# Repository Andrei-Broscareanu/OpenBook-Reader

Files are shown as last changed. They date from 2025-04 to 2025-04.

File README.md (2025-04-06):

# 📖 eBook Reader Portabil – ESP32-C6 Edition

Un eBook Reader cu consum redus, afișaj E-Ink și conectivitate modernă (Wi-Fi 6 & Bluetooth 5), construit în jurul microcontrollerului **ESP32-C6-WROOM-1-N8**.

---

## 🔧 Arhitectură Hardware

### 🧠 Microcontroller
- **ESP32-C6-WROOM-1-N8**
  - RISC-V core
  - Wi-Fi 6 și Bluetooth 5
  - Criptografie hardware integrată
  - Interfețe: SPI, I2C, GPIO

### 💾 Memorie
- **64MB NOR Flash** – W25Q512JVEIQ, conectată prin SPI
- **Slot microSD** – pentru stocare eBooks, conectat pe SPI separat

### 🔋 Alimentare
- **USB-C (PMF0501)** – intrare standard 5V
- **Protecție ESD (USBLC6-2SC6Y)** – pentru liniile USB
- **Încărcător Li-Po (MCP73831)** – pentru o celulă 3.7V, max 500mA
- **Baterie Li-Po 3.7V** – autonomie extinsă
- **Regulator LDO (MCP1700-3302E)** – convertește 5V la 3.3V

---

## 🖼️ Afișaj E-Ink

- Conector pentru ecrane de **1.54" E-Paper (200x200px)**
- Interfață: **SPI + GPIO**
- Circuit de alimentare:
  - Transistor Q3
  - Inductor L1
  - Diodă D2
- **Selector SJ1** – pentru tipul de display

---

## 📦 Periferice & Senzori

| Componentă | Funcție | Interfață | Pini ESP32-C6 |
|---|---|---|---|
| **BME688** | Temperatură, umiditate, presiune, VOCs | I2C | GPIO1 (SDA), GPIO2 (SCL) |
| **DS3231SN** | RTC – ceas timp real | I2C | GPIO1 (SDA), GPIO2 (SCL) |
| **MAX17048G-T10** | Fuel gauge baterie | I2C | GPIO1 (SDA), GPIO2 (SCL) |
| **Buton Reset** | Sistem reset | GPIO | GPIO0 |
| **Buton Boot** | Bootloader | GPIO | GPIO3 |
| **Qwiic/Stemma QT**| Extensii rapide I2C | I2C | GPIO1 (SDA), GPIO2 (SCL) |

---

## 🔌 Pini utilizați pe ESP32-C6

| Componentă | Interfață | Pini ESP32-C6 | Observații |
|---|---|---|---|
| SD Card | SPI | GPIO10, GPIO11, GPIO12, GPIO13 | Bus SPI dedicat |
| NOR Flash | SPI | GPIO6, GPIO7, GPIO8, GPIO9 | Bus SPI separat |
| E-Ink Display | SPI + GPIO | GPIO18, GPIO19, GPIO20, GPIO21 | Control ecran |
| Senzori + RTC | I2C | GPIO1 (SDA), GPIO2 (SCL) | Comun I2C |
| Butoane sistem | GPIO | GPIO0 (RST), GPIO3 (BOOT) | Control utilizator |
| Test Pads | GPIO/UART | GPIO17, GPIO22 | Debug/UART |

---

## ⚡ Estimare consum de energie

| Modul | Consum aproximativ |
|---|---|
| ESP32-C6 activ | ~80-100 mA |
| ESP32-C6 deep sleep | ~10 µA |
| E-Ink refresh | ~25 mA (temporar) |
| SD Card idle / acces | ~2 mA / ~50 mA |
| RTC + BME688 standby | ~3-5 µA |
| MAX17048 | ~3 µA |

**Autonomie estimată cu baterie Li-Po 500mAh:**
- Utilizare normală: **15-20 ore**
- Standby (deep sleep): **până la câteva săptămâni**

---

## 🧩 Design PCB și carcasă

- Blocuri separate: alimentare, MCU, afișaj, senzori
- Plan de masă comun și trasee optimizate
- Conectori accesibili extern (USB, afisaj, butoane)
- Carcasă 3D ergonomică și compactă
- Randări 3D disponibile

---

## ✅ Status proiect

- [x] Hardware complet funcțional
- [x] PCB finalizat și validat
- [x] Carcasă 3D completă
- [x] Optimizare consum energetic
- [x] Conectivitate Wi-Fi 6 și Bluetooth 5

---

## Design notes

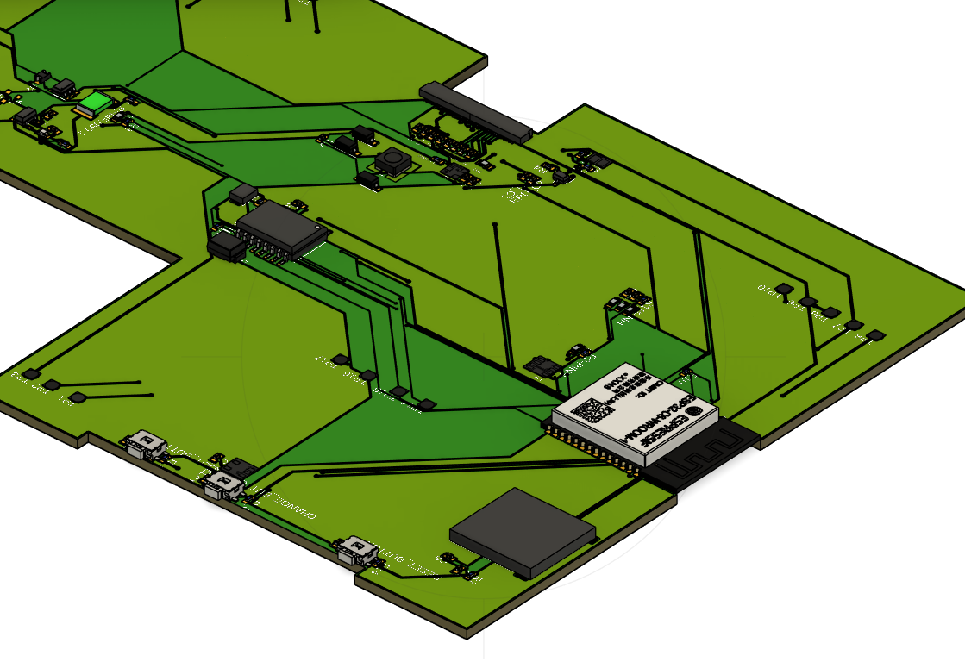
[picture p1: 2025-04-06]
Images/Captură de ecran 2025-04-06 132129.png

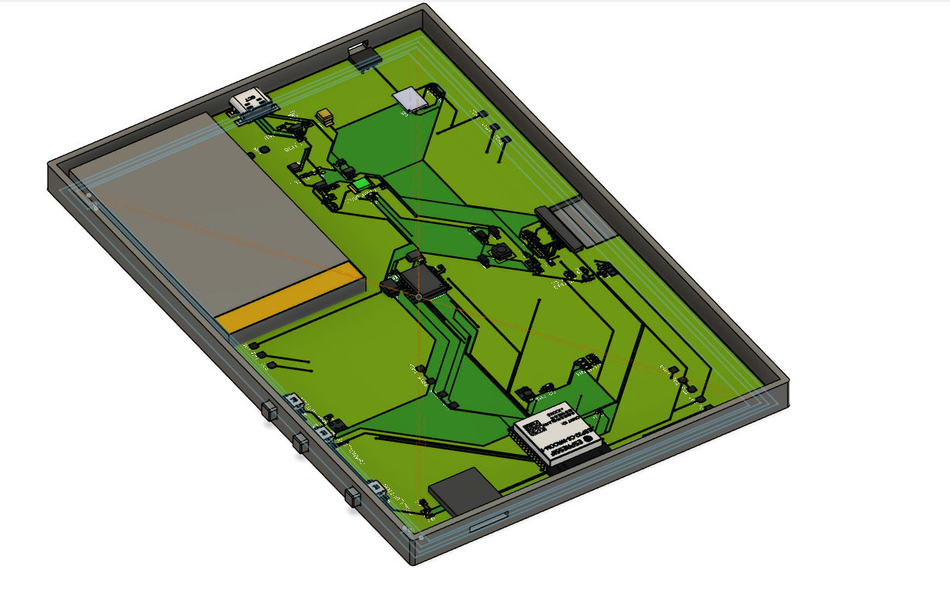
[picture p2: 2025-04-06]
Images/Captură de ecran 2025-04-06 132329.png

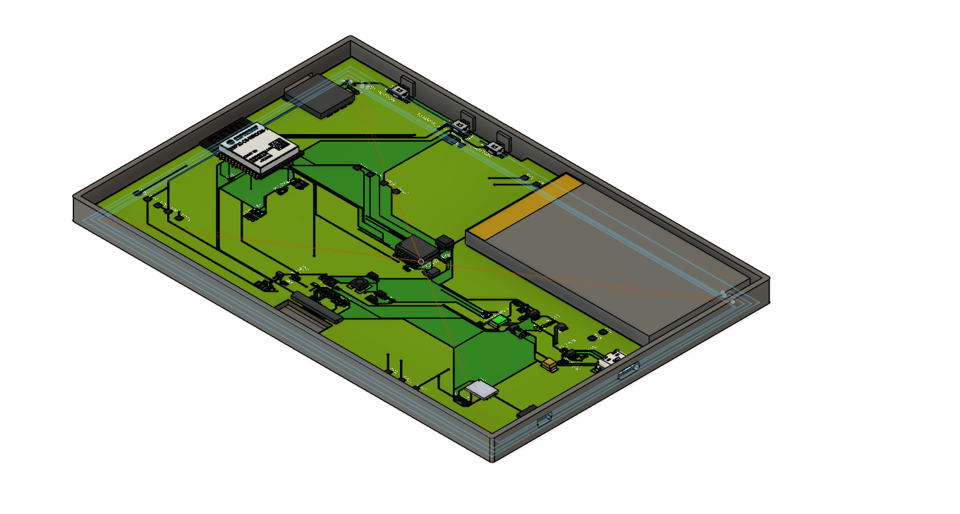
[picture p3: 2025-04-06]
Images/Captură de ecran 2025-04-06 132304.png

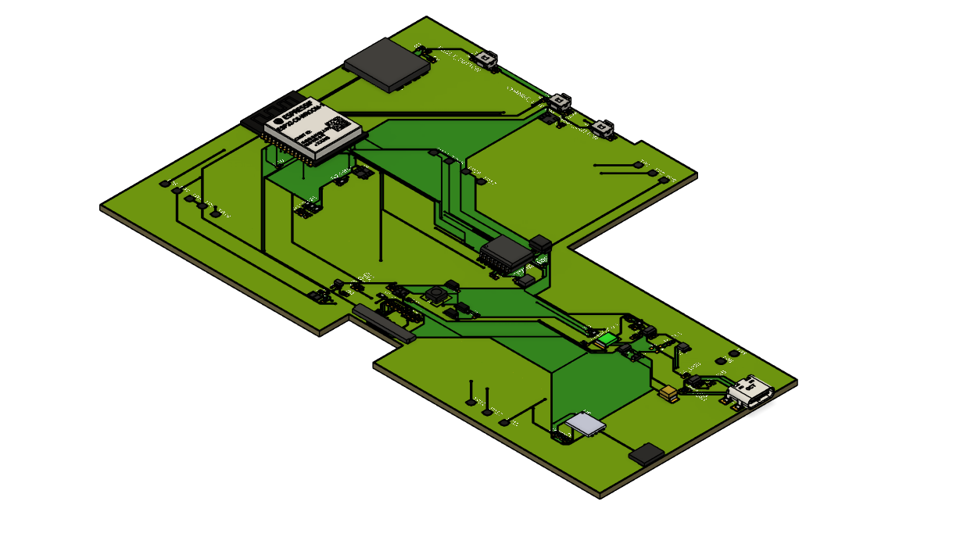
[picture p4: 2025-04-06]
Images/Captură de ecran 2025-04-06 130139.png

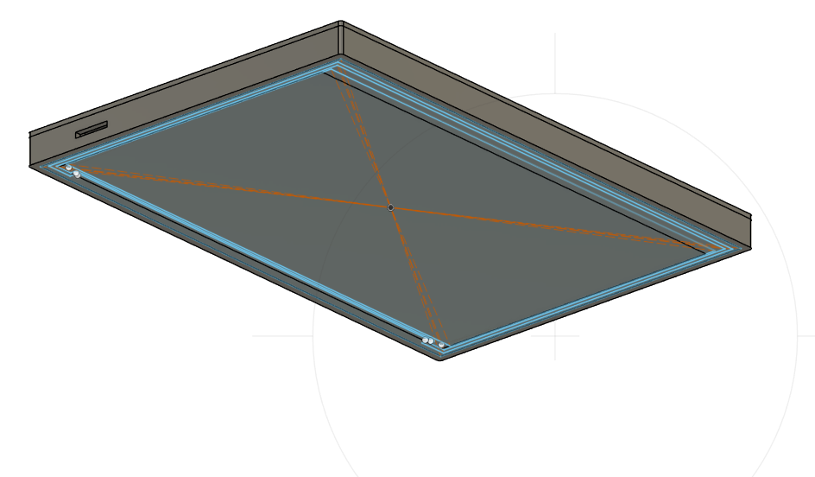
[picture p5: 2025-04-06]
Images/Captură de ecran 2025-04-06 132404.png

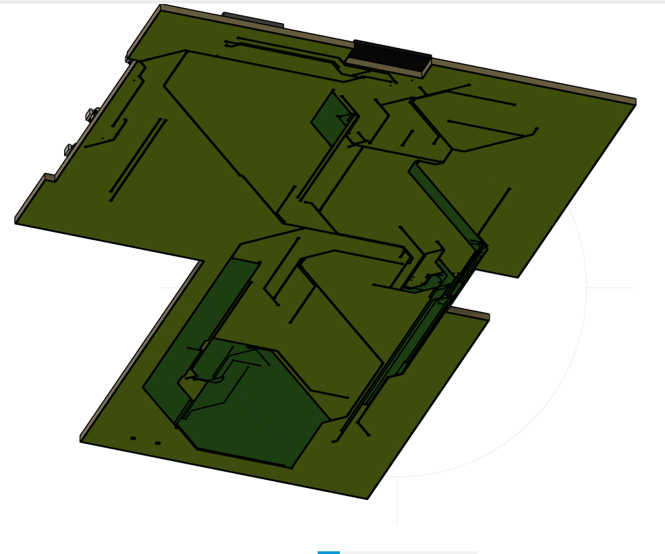
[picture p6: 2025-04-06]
Images/Captură de ecran 2025-04-06 132156.png

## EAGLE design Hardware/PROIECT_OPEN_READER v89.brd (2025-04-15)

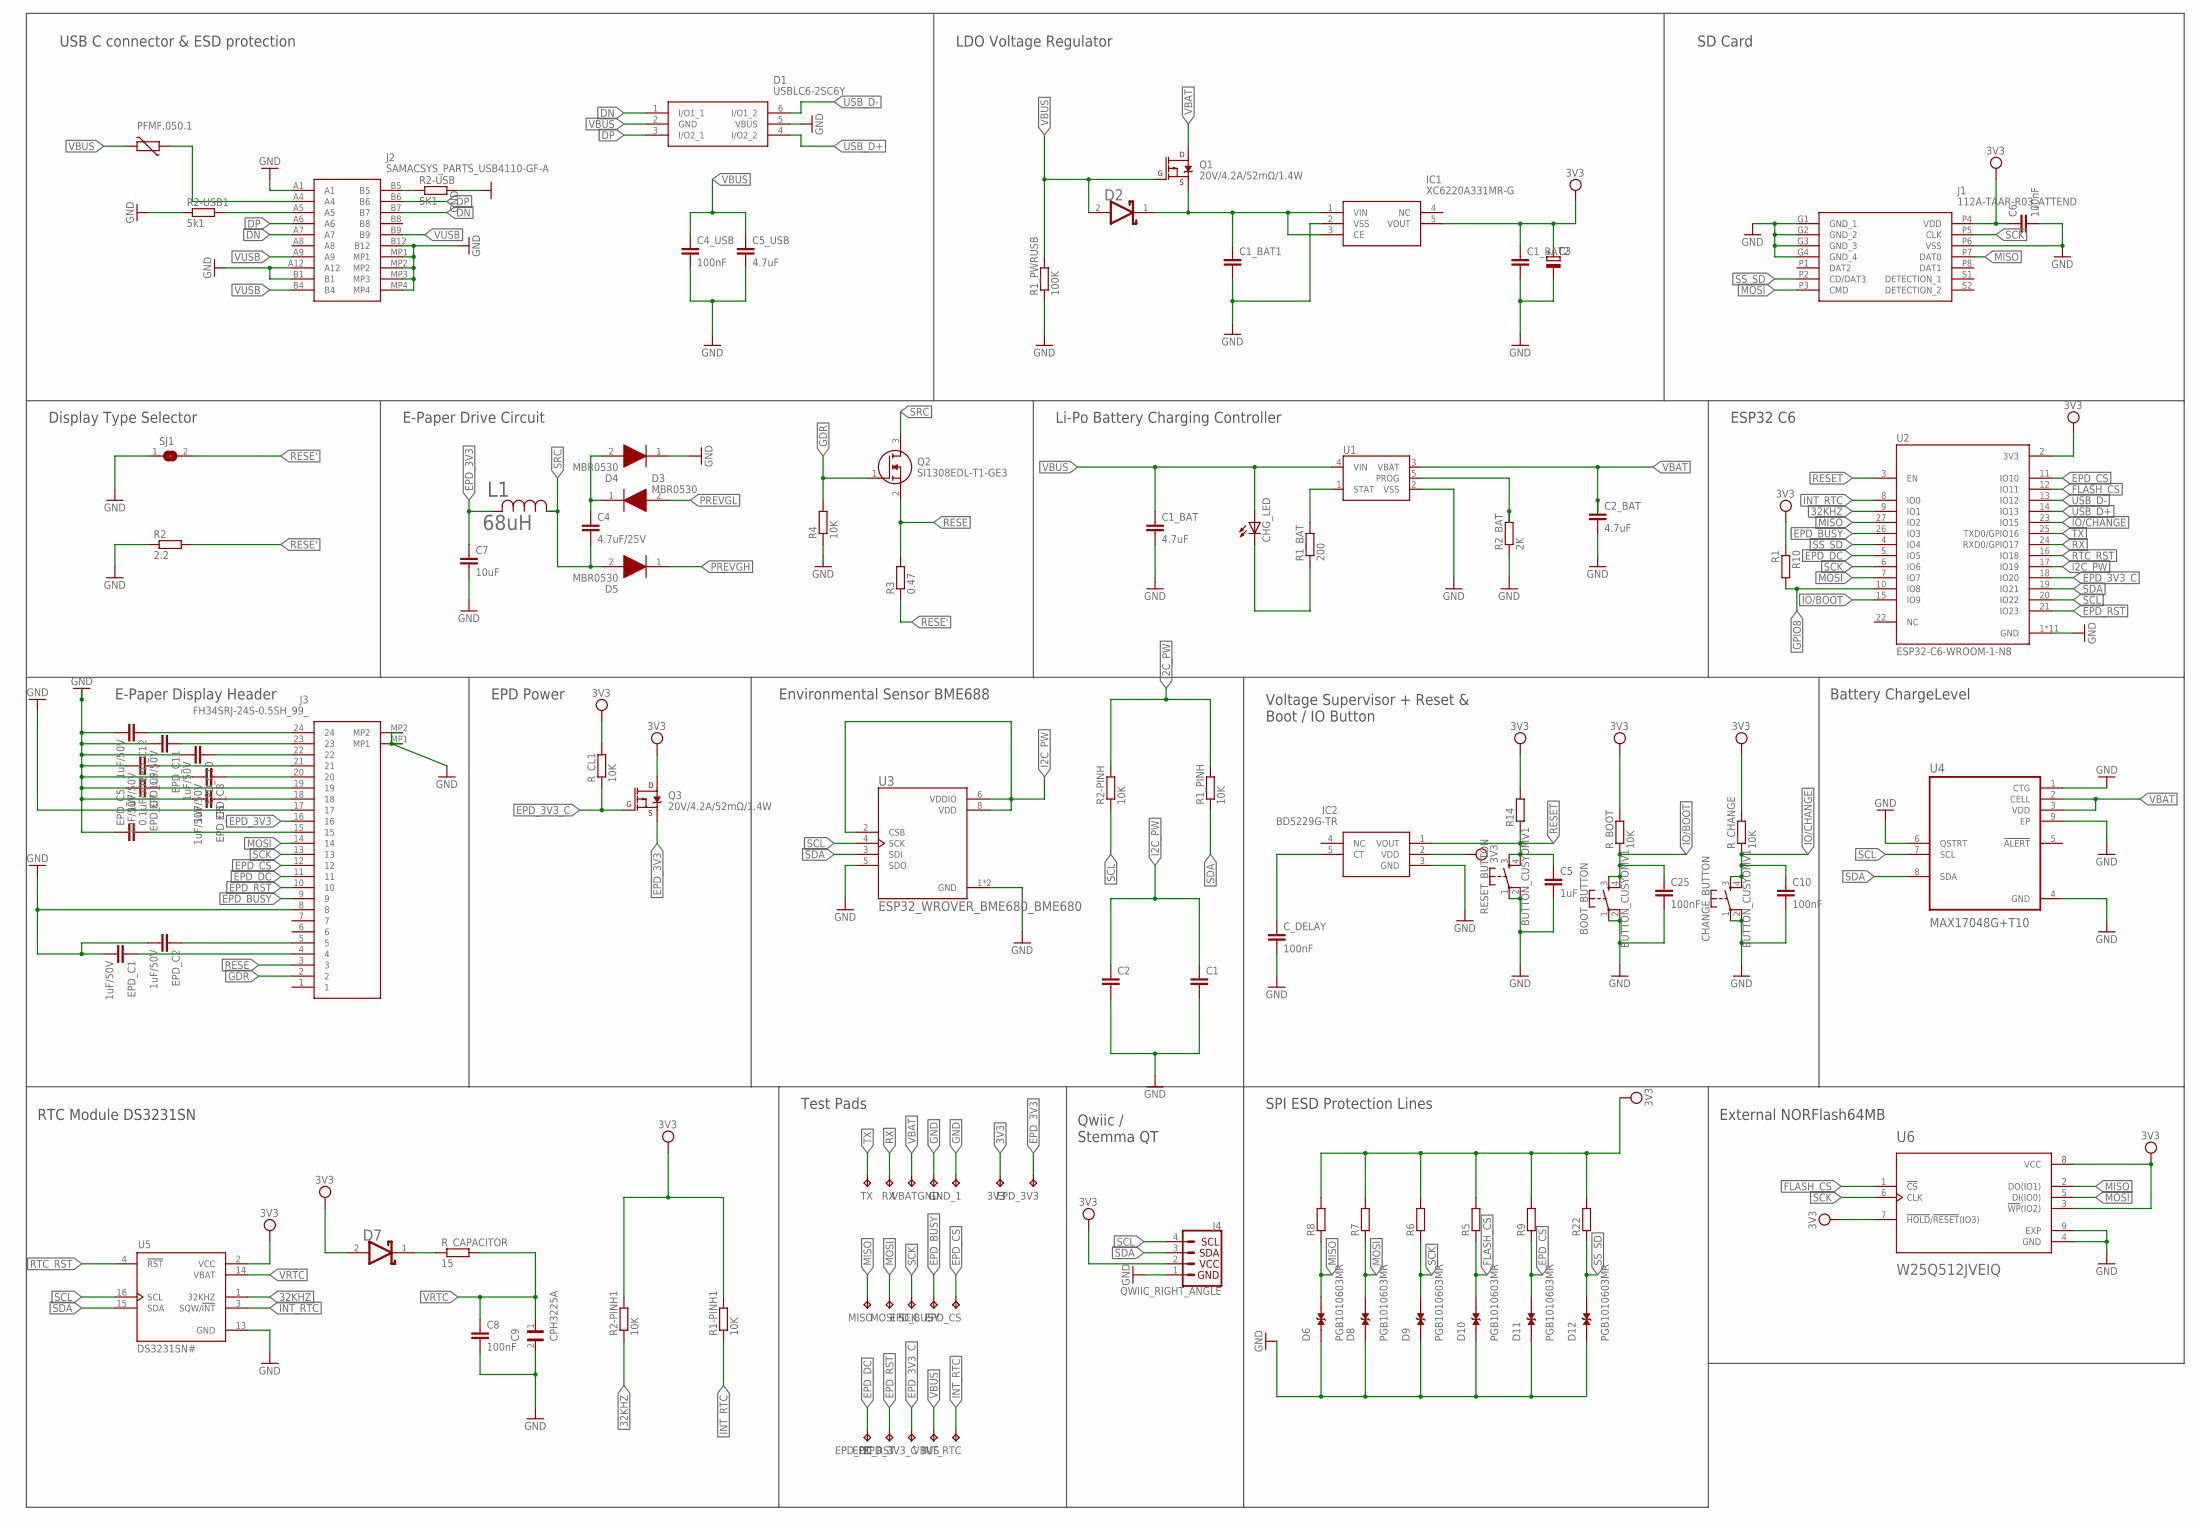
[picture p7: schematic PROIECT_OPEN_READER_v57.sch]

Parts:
3V3: TPTP20R; TP20R
BOOT_BUTTON: BUTTON_CUSYOMV1; MYBUTTON
C1, C1_BAT1, C1_BAT2, C2: EAGLE-LTSPICE_CC0402; EAGLE-LTSPICE_C0402
C1_BAT, C2_BAT, C5_USB: 4.7uF; EAGLE-LTSPICE_C0402
C3: RCL_CPOL-EUCT3528; RCL_CT3528
C4: 4.7uF/25V; EAGLE-LTSPICE_C0402
C4_USB, C6, C8, C10, C25: 100nF; EAGLE-LTSPICE_C0402
C5: 1uF; EAGLE-LTSPICE_C0402
C7: 10uF; EAGLE-LTSPICE_C0402
C9: CPH3225A; CAPCP3225X100N
CHANGE_BUTTON: BUTTON_CUSYOMV1; MYBUTTON
CHG_LED: ADAFRUIT_LEDCHIP-LED0603; ADAFRUIT_CHIP-LED0603
C_DELAY: 100nF; EAGLE-LTSPICE_C0402
D1: USBLC6-2SC6Y; SOT95P280X145-6N
D2, D7: ESP32_WROVER_AVX---SD0805S020S1R0_AVX_SD0805S020S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; ESP32_WROVER_AVX---SD0805S020S1R0_AVX_SD0805S020S1R0_0
D3, D4, D5: MBR0530; SOD3716X135N
D6, D8, D9, D10, D11, D12: PGB1010603MR; DIOC1608X36N
EPD_3V3, EPD_3V3_C: TPTP20R; TP20R
EPD_BUSY: TPTP20R; TP20R
EPD_C1, EPD_C2, EPD_C6, EPD_C7, EPD_C8, EPD_C9, EPD_C10, EPD_C11, EPD_C12: 1uF/50V; EAGLE-LTSPICE_C0402
EPD_C5: 0.1uF/50V; EAGLE-LTSPICE_C0402
EPD_CS: TPTP20R; TP20R
EPD_DC: TPTP20R; TP20R
EPD_RST: TPTP20R; TP20R
GND: TPTP20R; TP20R
GND_1: TPTP20R; TP20R
IC1: XC6220A331MR-G; SOT95P280X120-5N
IC2: BD5229G-TR; SOT95P280X125-5N
INT_RTC: TPTP20R; TP20R
J1: 112A-TAAR-R03_ATTEND; 112ATAARR03ATTEND
J2: SAMACSYS_PARTS_USB4110-GF-A; SAMACSYS_PARTS_USB4110GFA
J3: FH34SRJ-24S-0.5SH_99_; FH34SRJ24S05SH99
J4: QWIIC_RIGHT_ANGLE; JST04_1MM_RA
L1: 68uH; IND_4828-WE-TPC_WRE
MISO: TPTP20R; TP20R
MOSI: TPTP20R; TP20R
PFMF.050.1: ESP32C6_VARISTORCN1812; ESP32C6_VARISTOR_CT/CN1812
Q1, Q3: 20V/4.2A/52mΩ/1.4W; ESP32_WROVER_SPARKFUN-DISCRETESEMI_SOT23-3
Q2: SI1308EDL-T1-GE3; SOT65P210X110-3N
R1-PINH1, R1_PINH, R2-PINH, R2-PINH1, R4: 10K; ESP32_WROVER_EAGLE-LTSPICE_R0402
R1_BAT: 200; ESP32_WROVER_EAGLE-LTSPICE_R0402
R1_PWRUSB: 100K; ESP32_WROVER_EAGLE-LTSPICE_R0402
R2: 2.2; ESP32_WROVER_EAGLE-LTSPICE_R0402
R2-USB: 5K1; ESP32_WROVER_EAGLE-LTSPICE_R0402
R2-USB1: 5k1; ESP32_WROVER_EAGLE-LTSPICE_R0402
R2_BAT: 2K; ESP32_WROVER_EAGLE-LTSPICE_R0402
R3: 0.47; ESP32_WROVER_EAGLE-LTSPICE_R0402
R5, R6, R7, R8, R9, R14, R22: ESP32_WROVER_EAGLE-LTSPICE_RR0402; ESP32_WROVER_EAGLE-LTSPICE_R0402
R10: R1; ESP32_WROVER_EAGLE-LTSPICE_R0402
RESET_BUTTON: BUTTON_CUSYOMV1; MYBUTTON
RX: TPTP20R; TP20R
R_BOOT: 10K; ESP32_WROVER_EAGLE-LTSPICE_R0402
R_CAPACITOR: 15; ESP32_WROVER_EAGLE-LTSPICE_R0402
R_CHANGE: 10K; ESP32_WROVER_EAGLE-LTSPICE_R0402
R_CL1: 10K; ESP32_WROVER_EAGLE-LTSPICE_R0402
SCK: TPTP20R; TP20R
SJ1: SJ
TX: TPTP20R; TP20R
U1: ESP32_WROVER_SPARKFUN-IC-POWER_MCP73831; ESP32_WROVER_SPARKFUN-IC-POWER_SOT23-5
U2: ESP32-C6-WROOM-1-N8; XCVR_ESP32-C6-WROOM-1-N8
U3: ESP32_WROVER_BME680_BME680; ESP32_WROVER_BME680_PSON80P300X300X100-8N
U4: MAX17048G+T10; SON50P200X200X80-9N
U5: DS3231SN#; SOIC127P1032X265-16N
U6: W25Q512JVEIQ; SON127P600X800X80-9N
VBAT: TPTP20R; TP20R
VBUS: TPTP20R; TP20R

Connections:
3V3: 3V3.TP, C1_BAT2.1, C3.+, C6.1, D7.2 (ANODE), IC1.5 (VOUT), IC2.2 (VDD), J1.P4 (VDD), J4.2, Q3.3 (D), R1-PINH1.2, R2-PINH1.2, R5.2, R6.2, R7.2, R8.2, R9.2, R10.1, R14.2, R22.2, R_BOOT.2, R_CHANGE.2, R_CL1.2, U2.2 (3V3), U5.2 (VCC), U6.3 (!WP!(IO2)), U6.7 (!HOLD!/!RESET!(IO3)), U6.8 (VCC)
32KHZ: R2-PINH1.1, U2.9 (IO1), U5.1 (32KHZ)
DN: D1.1 (I/O1_1), J2.A7, J2.B7
DP: D1.3 (I/O2_1), J2.A6, J2.B6
EPD_3V3: C7.1, EPD_3V3.TP, J3.16, L1.2, Q3.2 (S)
EPD_3V3_C: EPD_3V3_C.TP, Q3.1 (G), R_CL1.1, U2.18 (IO20)
EPD_BUSY: EPD_BUSY.TP, J3.9, U2.26 (IO3)
EPD_CS: D11.2, EPD_CS.TP, J3.12, R9.1, U2.11 (IO10)
EPD_DC: EPD_DC.TP, J3.11, U2.5 (IO5)
EPD_RST: EPD_RST.TP, J3.10, U2.21 (IO23)
FLASH_CS: D10.2, R5.1, U2.12 (IO11), U6.1 (!CS)
GDR: J3.2, Q2.1 (G), R4.2
GND: BOOT_BUTTON.1, BOOT_BUTTON.2, C1.2, C1_BAT.2, C1_BAT1.2, C1_BAT2.2, C2.2, C2_BAT.2, C3.-, C4_USB.2, C5.2, C5_USB.2, C6.2, C7.2, C8.2, C9.2, C10.2, C25.2, CHANGE_BUTTON.1, CHANGE_BUTTON.2, C_DELAY.2, D1.5 (VBUS), D4.1 (K), D6.1, D8.1, D9.1, D10.1, D11.1, D12.1, EPD_C1.2, EPD_C2.2, EPD_C5.1, EPD_C6.2, EPD_C7.2, EPD_C8.2, EPD_C9.2, EPD_C10.2, EPD_C11.2, EPD_C12.2, GND.TP, GND_1.TP, IC1.2 (VSS), IC2.3 (GND), J1.G1 (GND_1), J1.G2 (GND_2), J1.G3 (GND_3), J1.G4 (GND_4), J1.P6 (VSS), J2.A1, J2.A12, J2.B1, J2.B12, J2.MP1, J2.MP2, J2.MP3, J2.MP4, J3.8, J3.17, J3.MP1, J3.MP2, J4.1, R1_PWRUSB.1, R2.1, R2-USB.2, R2-USB1.1, R2_BAT.1, R4.1, RESET_BUTTON.1, RESET_BUTTON.2, SJ1.1, U1.2 (VSS), U2.1 (GND), U2.28 (GND), U2.29_1 (GND), U2.29_2 (GND), U2.29_3 (GND), U2.29_4 (GND), U2.29_5 (GND), U2.29_6 (GND), U2.29_7 (GND), U2.29_8 (GND), U2.29_9 (GND), U3.1 (GND), U3.5 (SDO), U3.7 (GND), U4.1 (CTG), U4.4 (GND), U4.6 (QSTRT), U4.9 (EP), U5.13 (GND), U6.4 (GND), U6.9 (EXP)
GPIO8: R10.2, U2.10 (IO8)
I2C_PW: C1.1, C2.1, R1_PINH.2, R2-PINH.2, U2.17 (IO19), U3.2 (CSB), U3.6 (VDDIO), U3.8 (VDD)
INT_RTC: INT_RTC.TP, R1-PINH1.1, U2.8 (IO0), U5.3 (SQW/!INT)
IO/BOOT: BOOT_BUTTON.3, BOOT_BUTTON.4, C25.1, R_BOOT.1, U2.15 (IO9)
IO/CHANGE: C10.1, CHANGE_BUTTON.3, CHANGE_BUTTON.4, R_CHANGE.1, U2.23 (IO15)
MISO: D6.2, J1.P7 (DAT0), MISO.TP, R8.1, U2.27 (IO2), U6.2 (DO(IO1))
MOSI: D8.2, J1.P3 (CMD), J3.14, MOSI.TP, R7.1, U2.7 (IO7), U6.5 (DI(IO0))
unnamed: J2.A4, PFMF.050.1.1
unnamed: J2.A5, R2-USB1.2
unnamed: J2.B5, R2-USB.1
unnamed: C1_BAT1.1, D2.1 (CATHODE), IC1.1 (VIN), IC1.3 (CE), Q1.2 (S)
unnamed: EPD_C12.1, J3.24
unnamed: EPD_C11.1, J3.23
unnamed: C4.1, D3.1 (K), D4.2 (A)
unnamed: R2_BAT.2, U1.5 (PROG)
unnamed: EPD_C10.1, J3.22
unnamed: EPD_C9.1, J3.21
unnamed: CHG_LED.C, R1_BAT.1
unnamed: R1_BAT.2, U1.1 (STAT)
unnamed: EPD_C8.1, J3.20
unnamed: EPD_C7.1, J3.19
unnamed: EPD_C6.1, J3.18
unnamed: C_DELAY.1, IC2.5 (CT)
unnamed: EPD_C5.2, J3.15
unnamed: EPD_C2.1, J3.5
unnamed: EPD_C1.1, J3.4
unnamed: D7.1 (CATHODE), R_CAPACITOR.1
PREVGH: D5.1 (K)
PREVGL: D3.2 (A)
RESE: J3.3, Q2.2 (S), R3.2
RESE': R2.2, R3.1, SJ1.2
RESET: C5.1, IC2.1 (VOUT), R14.1, RESET_BUTTON.3, RESET_BUTTON.4, U2.3 (EN)
RTC_RST: U2.16 (IO18), U5.4 (!RST)
RX: RX.TP, U2.24 (RXD0/GPIO17)
SCK: D9.2, J1.P5 (CLK), J3.13, R6.1, SCK.TP, U2.6 (IO6), U6.6 (CLK)
SCL: J4.4, R2-PINH.1, U2.20 (IO22), U3.4 (SCK), U4.7 (SCL), U5.16 (SCL)
SDA: J4.3, R1_PINH.1, U2.19 (IO21), U3.3 (SDI), U4.8 (SDA), U5.15 (SDA)
SRC: C4.2, D5.2 (A), L1.1, Q2.3 (D)
SS_SD: D12.2, J1.P2 (CD/DAT3), R22.1, U2.4 (IO4)
TX: TX.TP, U2.25 (TXD0/GPIO16)
USB_D+: D1.4 (I/O2_2), U2.14 (IO13)
USB_D-: D1.6 (I/O1_2), U2.13 (IO12)
VBAT: C2_BAT.1, Q1.3 (D), U1.3 (VBAT), U4.2 (CELL), U4.3 (VDD), VBAT.TP
VBUS: C1_BAT.1, C4_USB.1, C5_USB.1, CHG_LED.A, D1.2 (GND), D2.2 (ANODE), PFMF.050.1.2, Q1.1 (G), R1_PWRUSB.2, U1.4 (VIN), VBUS.TP
VRTC: C8.1, C9.1, R_CAPACITOR.2, U5.14 (VBAT)
VUSB: J2.A9, J2.B4, J2.B9

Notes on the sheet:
USB C connector & ESD protection
LDO Voltage Regulator
SD Card
Display Type Selector
E-Paper Drive Circuit
Li-Po Battery Charging Controller
ESP32 C6
E-Paper Display Header
EPD Power
Environmental Sensor BME688
Voltage Supervisor + Reset & Boot / IO Button
Battery ChargeLevel
RTC Module DS3231SN
Test Pads
Qwiic / Stemma QT
SPI ESD Protection Lines
External NORFlash64MB

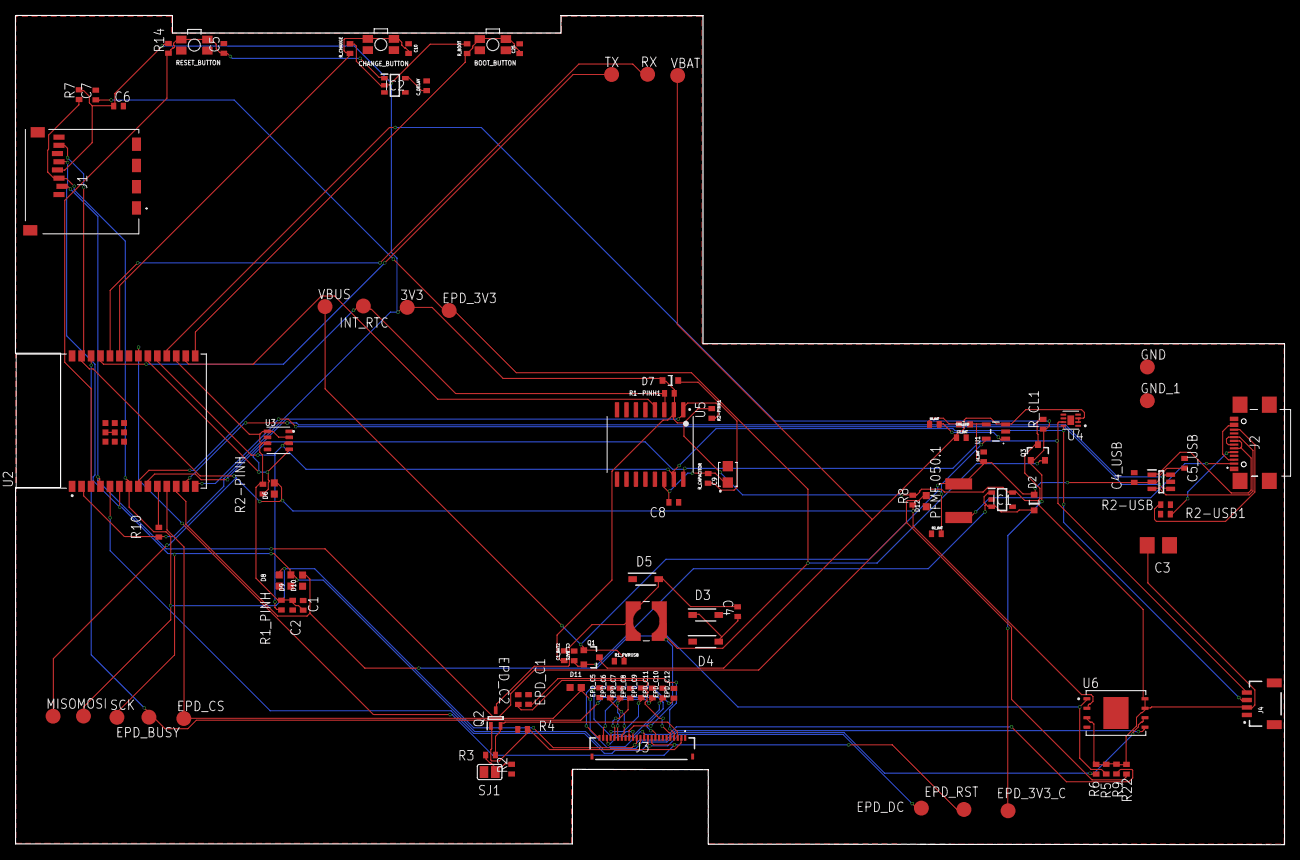
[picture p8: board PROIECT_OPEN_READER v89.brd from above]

Board: 2 copper layers, 170.2 x 111.2 mm, 103 parts (0 on the bottom side), 57 nets.

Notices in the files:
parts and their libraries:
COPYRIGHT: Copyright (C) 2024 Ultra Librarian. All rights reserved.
